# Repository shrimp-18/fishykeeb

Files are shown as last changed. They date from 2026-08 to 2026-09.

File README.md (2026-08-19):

# fishykeeb

FishyKeeb is a sting-ray shaped compact 4X1 customizable macroboard. It is made for Sunbeam Delhi! It is powered by a XIAORP2040 and also has 2 RGB NeoPixel LEDs. Uses Cherry MX Red Switches. 

---

ZINE

<br>

## How it works

- Plug the XIAO into your computer and upload firmware through the Arduino IDE given in this repository or use the QMK Firmware (https://qmk.fm/)
- The macropad is now ready to use! (pretty simple init)

  <br>


<br>

## Why Fishy Keeb was made?

Fishy Keeb is made to be given out as a prize to winners in Sunbeam Delhi. It is a very cool-looking macro-pad which you can customize to do anything you'd like!

<br>

## Schematic


<br>

## PCB

<br>


<br>

## The Case

<br>



## Fusion Files: https://a360.co/4wC0P4i

<br>

## How to Build

1. Download the KiCad files and then generate gerber files. <br>
2. go to jlcpcb.com and place the order for the pcb!
3. Buy all components listed in the BOM. <br>
4. On receiving your PCB, solder the XIAO and the MX Cherry switches to the PCB.
5. Place the keycaps on the switches.
6. Use the CAD files given in the repo to 3D-print the top and bottom case of the fishy keeb.
7. Place the assembled PCB in the bottom case and close it by aligning the top case.
8. Use M3 Screws to hold the two parts of the cases together in place.
9. Connect the XIAO to your computer and flash it with the firmware (either the .ino file using Arduino IDE or by using qmk.fm).
10. Your fishy keeb is ready to use!!

## Bill of Materials (BOM)

| S.No. | Reference | Value | Product Name | Note | Qty | Cost (INR) | Link |
|---|---|---|---|---|-----|---|---|
| 1 | U1 | XIAO-RP2040-DIP | XIAO RP2040 | on the pcb | 1 | 529 | [Link](https://robu.in/product/seeed-studio-xiao-rp2040-v1-0/) |
| 2 | SW1, SW2, SW3, SW4 | SW_Push | Cherry MX Switches | on the pcb | 4 | 488 | [Link](https://www.mouser.in/en/ProductDetail/CHERRY/MX2A-E1NB) |
| 3 | D1, D2 | SK6812MINI | LEDs | on the pcb | 2 | 300 | [Link](https://shiroganelab.com/en/products/keyball-rgb-led-sk6812mini-e) |
| 4 | — | — | PCB | the pcb | 1 | 190 | [Link](https://cart.jlcpcb.com/quote) |
| 5 | — | — | Bottom Case | 3D printed | 1 | 408 | [Link](https://zbotic.in/product/online-3d-printing-service/) |
| 6 | — | — | Top Case | 3D printed | 1 | 257 | [Link](https://zbotic.in/product/online-3d-printing-service/) |
| 7 | — | — | Screws | just screws | 4 | 6 | [Link](https://onlyscrews.in/products/phillips-csk-m3-x-10mm-pack-of-20) |
| 8 | — | — | Key Caps | just keycaps | 4 | 32 | [Link](https://rajivelectronics.com/product/cherry-mx-compatible-transparent-keycap-mechanical-keyboard-keycap) |

**Total estimated cost:** ₹2210

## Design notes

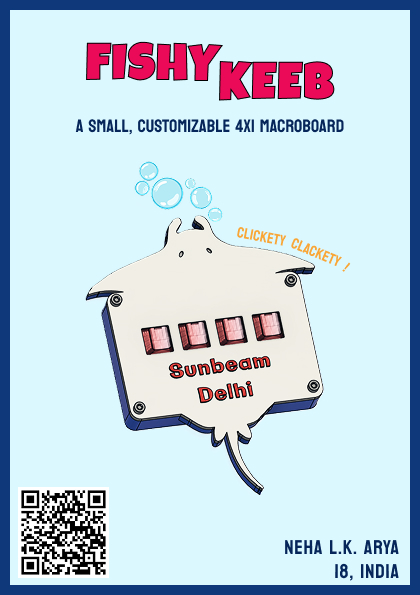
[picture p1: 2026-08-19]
images/ZINE.jpg

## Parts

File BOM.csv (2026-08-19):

S. No. | Reference | Value | Product Name | Note | Quantity | Cost(in INR) | Link
1 | U1 | XIAO-RP2040-DIP | XIAO RP2040 | on the pcb | 1 | 529 | https://robu.in/product/seeed-studio-xiao-rp2040-v1-0/
2 | SW1, SW2, SW3, SW4 | SW_Push | Cherry MX Switches | on the pcb | 4 | 488 | https://www.mouser.in/en/ProductDetail/CHERRY/MX2A-E1NB
3 | D1, D2 | SK6812MINI | LEDs | on the pcb | 2 | 300 | https://shiroganelab.com/en/products/keyball-rgb-led-sk6812mini-e
4 |  |  | PCB | the pcb | 1 | 190 | https://cart.jlcpcb.com/quote
5 |  |  | Bottom Case | 3d printed | 1 | 408 | https://zbotic.in/product/online-3d-printing-service/
6 |  |  | Top Case | 3dprinted | 1 | 257 | https://zbotic.in/product/online-3d-printing-service/
7 |  |  | Screws | just screws | 4 | 6 | https://onlyscrews.in/products/phillips-csk-m3-x-10mm-pack-of-20
8 |  |  | Key Caps | just keycaps | 4 | 32 | https://rajivelectronics.com/product/cherry-mx-compatible-transparent-keycap-mechanical-keyboard-keycap
 |  |  |  |  | Total: | 2210

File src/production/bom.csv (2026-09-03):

Designator | Footprint | Quantity | Value | LCSC Part #
D1, D2 | LED_SK6812MINI_PLCC4_3.5x3.5mm_P1.75mm | 2 | SK6812MINI
SW1, SW2, SW3, SW4 | SW_Cherry_MX_1.00u_PCB | 4 | SW_Push
U1 | XIAO-RP2040-DIP | 1 | XIAO-RP2040-DIP

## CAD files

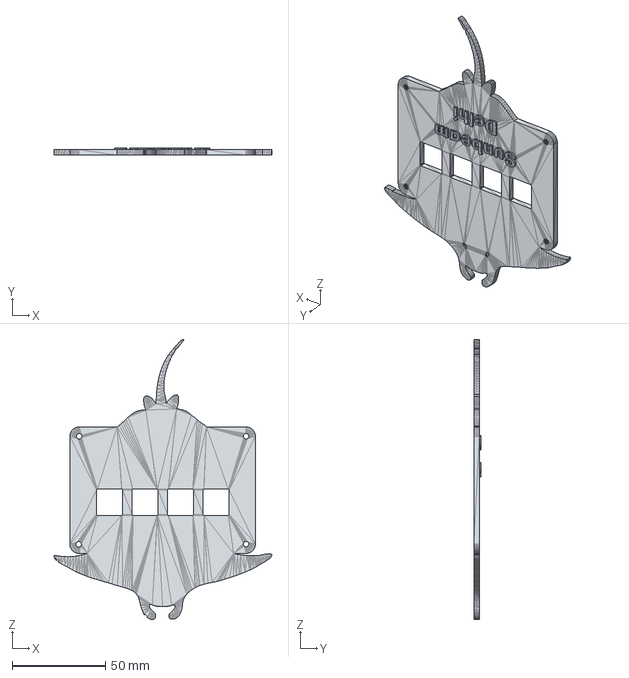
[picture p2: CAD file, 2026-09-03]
src/cad/top_case.step
116.7 x 4.00 x 150.1 mm

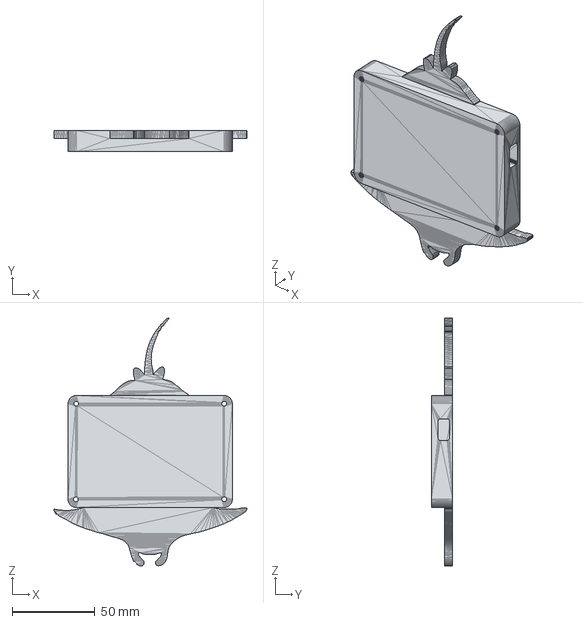
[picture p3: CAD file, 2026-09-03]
src/cad/bottom_case.step
116.7 x 13.0 x 150.1 mm

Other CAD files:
src/cad/bottom_case.stl
src/cad/fishykeeb_case.f3z
src/cad/top_case.stl

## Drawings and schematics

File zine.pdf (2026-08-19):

# FISHYKEEB

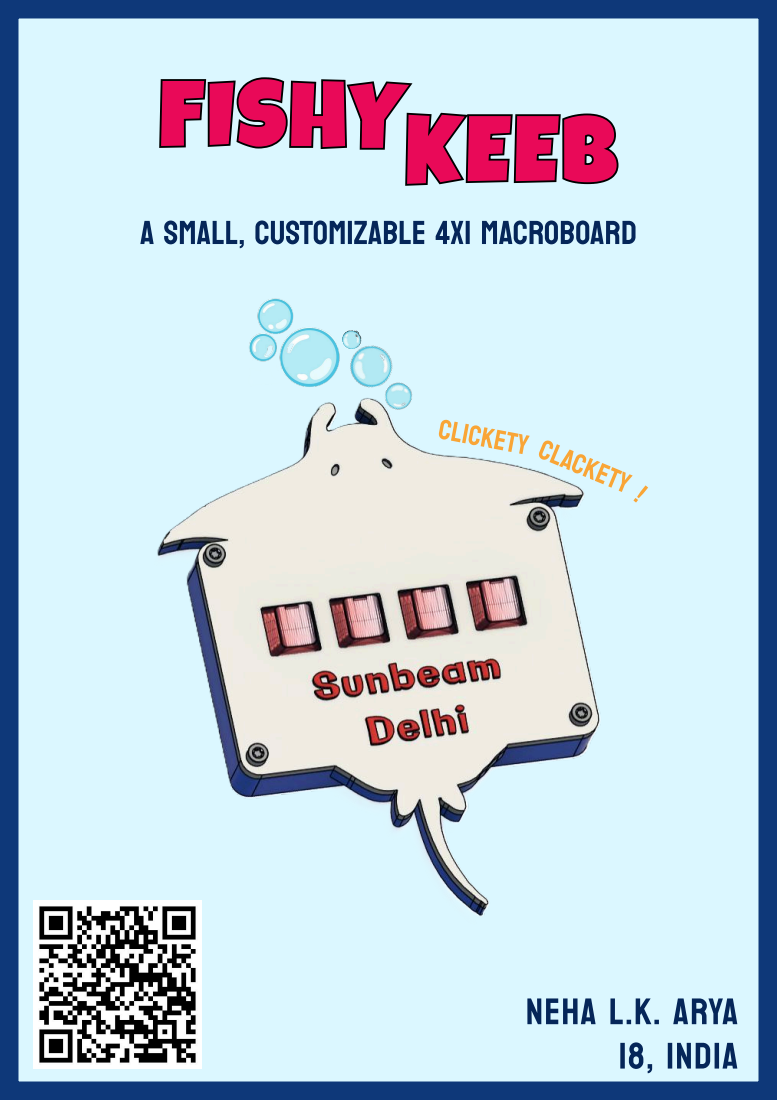
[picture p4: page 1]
CLICKETY CLACKETY !; Neha L.K. ARYA 18, INDIA

A SMALL, CUSTOMIZABLE 4X1 MACROBOARD

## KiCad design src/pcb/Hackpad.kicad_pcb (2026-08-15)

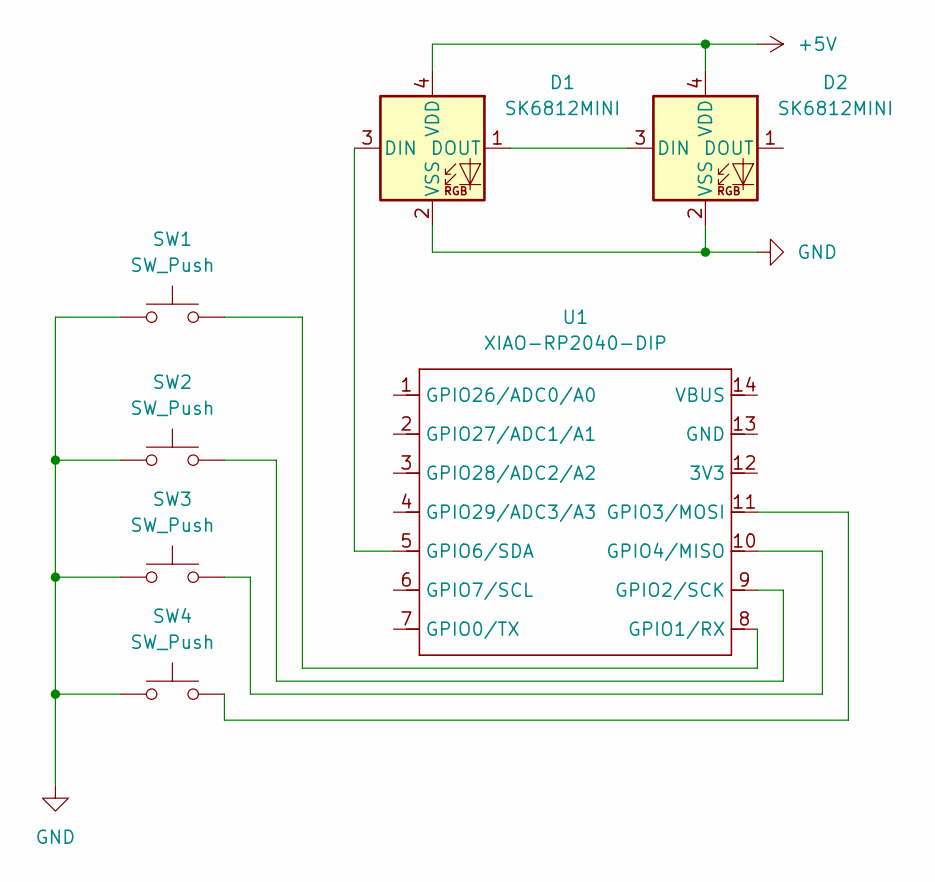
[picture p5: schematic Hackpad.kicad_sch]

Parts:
D1, D2: SK6812MINI; LED_SK6812MINI_PLCC4_3.5x3.5mm_P1.75mm
SW1, SW2, SW3, SW4: SW_Push; SW_Cherry_MX_1.00u_PCB
U1: XIAO-RP2040-DIP

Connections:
+5V: D1.4 (VDD), D2.4 (VDD)
GND: D1.2 (VSS), D2.2 (VSS), SW1.1, SW2.1, SW3.1, SW4.1
unnamed: D1.3 (DIN), U1.5 (GPIO6/SDA)
unnamed: D1.1 (DOUT), D2.3 (DIN)
unnamed: SW1.2, U1.8 (GPIO1/RX)
unnamed: SW2.2, U1.9 (GPIO2/SCK)
unnamed: SW4.2, U1.11 (GPIO3/MOSI)
unnamed: SW3.2, U1.10 (GPIO4/MISO)

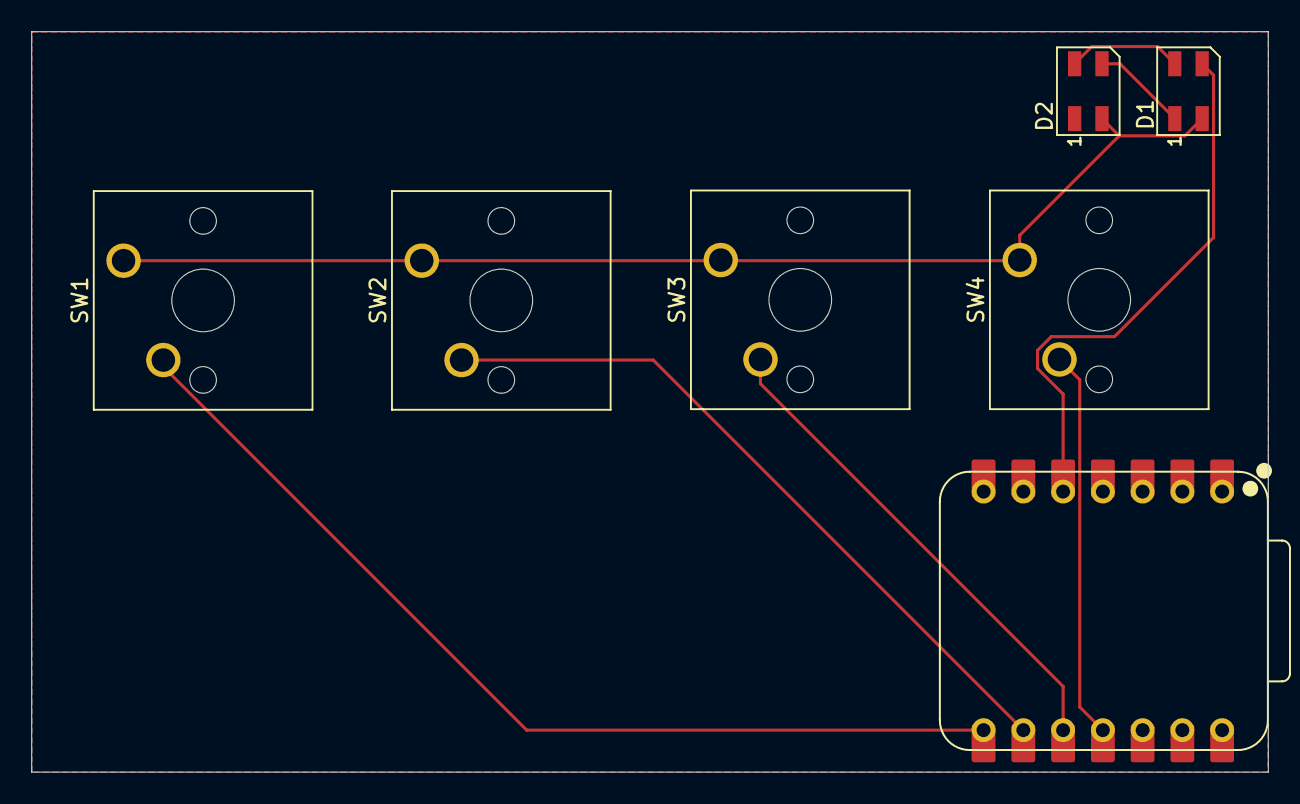
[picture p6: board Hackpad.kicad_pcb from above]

Board: 2 copper layers, 79.0 x 47.3 mm, 7 parts (0 on the bottom side), 8 nets.

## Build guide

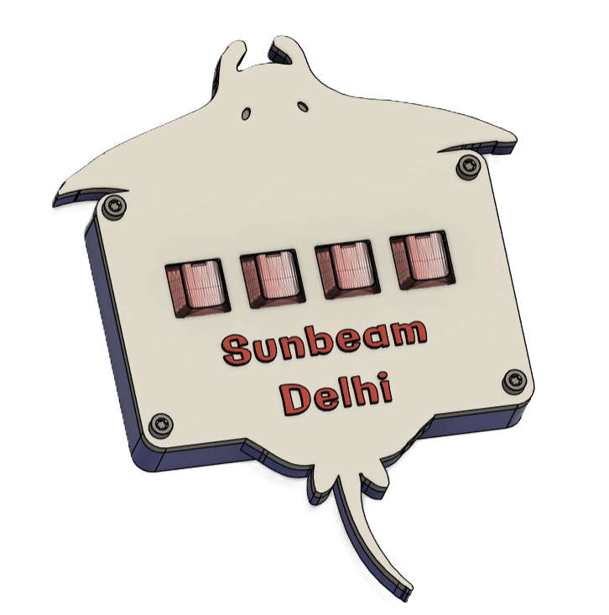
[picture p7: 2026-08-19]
images/fullassembly.png

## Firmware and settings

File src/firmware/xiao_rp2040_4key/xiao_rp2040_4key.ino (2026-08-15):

#include "Keyboard.h"
#include <Adafruit_NeoPixel.h>

const uint8_t KEY_PINS[4] = {D4, D7, D8, D10};
enum KeyAction { SINGLE_KEY, COMBO_KEY };

struct KeyMap {
  KeyAction type;
  uint8_t modifier;   
  uint8_t key;       
};

KeyMap keymap[4] = {
  { SINGLE_KEY, 0,             'a' },                 // SW1 -> 'a'
  { SINGLE_KEY, 0,             'b' },                 // SW2 -> 'b'
  { SINGLE_KEY, 0,             KEY_RETURN },           // SW3 -> Enter
  { COMBO_KEY,  KEY_LEFT_CTRL, 'c' },                  // SW4 -> Ctrl+C
};


const uint16_t DEBOUNCE_MS = 15;

bool lastReading[4]   = {HIGH, HIGH, HIGH, HIGH};
bool stableState[4]   = {HIGH, HIGH, HIGH, HIGH};
unsigned long lastChangeTime[4] = {0, 0, 0, 0};
-
#define LED_PIN     D3
#define LED_COUNT   2

const uint8_t BACKLIGHT_R = 20;
const uint8_t BACKLIGHT_G = 20;
const uint8_t BACKLIGHT_B = 30;

const uint8_t BACKLIGHT_BRIGHTNESS = 40;

Adafruit_NeoPixel strip(LED_COUNT, LED_PIN, NEO_GRB + NEO_KHZ800);

void sendKey(const KeyMap &km, bool press) {
  if (km.type == SINGLE_KEY) {
    if (press) Keyboard.press(km.key);
    else       Keyboard.release(km.key);
  } else {
    if (press) {
      Keyboard.press(km.modifier);
      Keyboard.press(km.key);
    } else {
      Keyboard.release(km.key);
      Keyboard.release(km.modifier);
    }
  }
}

void setup() {
  for (uint8_t i = 0; i < 4; i++) {
    pinMode(KEY_PINS[i], INPUT_PULLUP);
  }
  Keyboard.begin();

  strip.begin();
  strip.setBrightness(BACKLIGHT_BRIGHTNESS);
  for (uint8_t i = 0; i < LED_COUNT; i++) {
    strip.setPixelColor(i, strip.Color(BACKLIGHT_R, BACKLIGHT_G, BACKLIGHT_B));
  }
  strip.show();
}

void loop() {
  unsigned long now = millis();

  for (uint8_t i = 0; i < 4; i++) {
    bool reading = digitalRead(KEY_PINS[i]);

    if (reading != lastReading[i]) {
      lastChangeTime[i] = now;
      lastReading[i] = reading;
    }

    if ((now - lastChangeTime[i]) > DEBOUNCE_MS && reading != stableState[i]) {
      stableState[i] = reading;

      if (stableState[i] == LOW) {
        sendKey(keymap[i], true);
      } else {
        sendKey(keymap[i], false);
      }
    }
  }
}

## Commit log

2026-08-15 gnd fill
    [Hackpad.kicad_pcb]
2026-08-19 polished stuff
    [BOM.csv]
2026-08-19 fixed bom
    [BOM.csv]
2026-08-19 fixedbom fs
    [BOM.csv]
2026-08-19 still fixing ugh
    [BOM.csv]
2026-09-03 added step files
    [bottom_case.step, top_case.step]
2026-09-03 added gerber
    [Hackpad-B_Cu.gbr, Hackpad-B_Mask.gbr, Hackpad-B_Paste.gbr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]
